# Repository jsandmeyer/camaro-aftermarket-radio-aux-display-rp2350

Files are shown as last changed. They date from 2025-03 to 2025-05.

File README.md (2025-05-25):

## Camaro Temperature & Reverse Sensor Display Shim - RP2350

Picture of the assembled circuit

### Differences from [other repository](https://github.com/jsandmeyer/camaro-aftermarket-radio-aux-display)

This version uses an RP2350 (Raspberry Pi Pico 2 IC) instead of an ATMEGA328PB (Arduino Uno mod).

It takes advantage of the two cores so it can:
1. Listen to the CANBus while rendering is happening, without interrupting either
2. Listen to the CANBus without a CAN controller

### Summary

This provides resources to help you build something to get the temperature display of a PAC RPK5-GM4102 (or 4101) to function while using a Maestro RR instead of the box that came with the PAC kit.
This is useful if you want to have the Maestro functions to get/update vehicle data, but have the nice function and appearance of the OEM-style HVAC knobs provided by the PAC kit.

### Important
This project is not endorsed by GM, the makers of any trim kits (PAC, iDatalink, etc) or my aftermarket radio, any forum or their users, or anyone else, including any entities named in this repository.
It is a personal project that I have completed, and I have accepted a risk to my own property by building and installing this project.

This project (except for PCB footprints supplied by KiCad's included files) is licensed under the MIT license.
Please read the attached LICENSE document.
All code was written by myself, based on documentation provided by libraries or electronic part providers.
All PCB design (except for some footprints) was completed by myself.

### Background

[This forum post on camaro5.com](https://www.camaro5.com/forums/showthread.php?t=588249) goes over the process of combining the two dash kit elements.
Note the OP and others never got the temperature display to work.
This is because the PAC trim component's harness does not have CANBUS access, and the PAC controller was relaying the temperature (and possibly other data) over the Serial line running between the radio and HVAC harnesses.

### Goal

My goal was simply to display the temperature on the OLED.
In the process of design, I also decied to have it show backup sensor data.
The original MyLink radio showed a triangle with an exclamation point in one of five positions over the backup camera when reversing, and it would change color and flash depending on distance.
I wanted to display something similar on the OLED when reversing, because no aftermarket radios seem to support showing the backup sensor data AND camera view at the same time!
The latest version of this module is also able to determine whether the car is displaying metric or imperial units, so there is no need to adjust the jumper on the PCB.

### Reverse Engineering the Hardware

I was able to do some reverse engineering of the PAC RPK5, but without a logic analyzer or serial reading device, I could not do so completely.
I did determine that if I depinned the PAC harness to include only power input, net 5060 low-speed GMLAN, and net 7458 serial data, it would power on and the temperature would display.
However, if I disconnected the TX pin on the PAC controller's internal CANBUS modem (as suggested by its documentation, would force it into "read-only" mode) it would fail completely.
I also discovered that the OLED board used by PAC is a very standard SSD1306 SPI model, and it's roughly equivalent to something you could buy off a hobby site - and the cable connector is also a standard Molex PicoBlade (though the included cable is a crossover cable, likely not made by Molex).

### Reverse Engineering the CANBUS

#### Hardware and Software

I used an Arduino Uno and the [Sparkfun CANBUS shield](https://www.sparkfun.com/products/13262) to prove viability.
With this setup, I was able to snoop on my car's low-speed CANBUS (net 5060) via the main ODB connector using pin 1 for CAN_H and pin 4 for CAN_L and GND.
Using the [mcp_can library](https://github.com/coryjfowler/MCP_CAN_lib) I was able to read temperature and other data.
Eventually, some light googling got me [some details](https://docs.google.com/spreadsheets/d/1pFdixF6W0XK4SR6pXHIlZaFRo9qM5XmAWOK7JcAQdDM/) regarding CANBUS IDs for this car and for other GM cars.

My configuration for this was to:
* Call `CAN0.begin(MCP_STDEXT, CAN_33K3BPS, MCPHZ)` to initialize low-speed CANBUS at 33.3k.
* To configure the filters, I used online resources to try to determine what different ARB IDs meant, and in some cases, even turned off filtering and simply looked through the stream for messages.
* Call `CAN0.setMode(MCP_LISTENONLY)` for read-only CANBUS operation

#### Hardware V2

After confirming this configuration, I switched to using a bare ATMEGA328P chip (similar to the VQFN package I would use in production) and a MCP25625 CAN controller with transciever.
I added ferrite beads to the OLED connector after seeing that PAC decided to use them in their controller board.
I also added a switch to allow selection of Metric vs Imperial units.

#### Hardware V3

This is the first production version.
I added a nice TI power supply designed via Webench, soldered everything down, and also used a jumper to select Metric vs Imperail units (in place of the switch).
Some SMT components are slightly different, like using an AMEGA328PB instead of the ATMEGA328P, or the different footprint of the oscillator.

#### Hardware V6

Versions 4 and 5 had issues which prevented them from going to production.
This version includes mounting holes, extra power supply filtering, a watchdog to reboot the MCU if there are too many errors during boot, and auto-sensing of temperature/distance units instead of using a jumper.
The circuit also uses the 3.3V power supply for all logic except for the CAN transciever, which runs on the base 5V.

#### Hardware V7

This uses an RP2350 MCU instead of an ATMEGA328PB.
See the notes above.

It also uses a TCAN332 transciever instead of the MCP25625 (MCP2551-style).
The IC is effectively a drop-in replacement for the MCP-2551 (except that no slope control resistor is needed).
The main benefit is that it runs on 3.3V, so only one power suppy is necessary (in addition to the 1.1V inside the RP2350).

#### Logs

Temperature was easy to figure out, and was my first step.

For my 2014 Camaro, it comes in as 0x10424060 (raw header), or 0x212 (with mask).
The second byte `buf[1]` contains the temperature... kind-of.
You have to divide the hex value by two, and subtract 40, to get degrees in celsius.

The backup sensors took more work to understand, but were still straightforward.

I found that they were streaming data on 0x103A80BB (raw header), or 0x1D4 (with mask).

The *second nibble* of the first byte `buf[0] & 0x0F` indicates the park-assist staus.
A value of `0` indicates park-assist is ON, and a value of `F` indicates it is OFF.
The *first nibble* `buf[0] & 0xF0` seems related to something else, and also seemed to vary.

The Bosch parking assist unit seems to report the direction and distance to the *closest* object only.
The second byte `buf[1]` contains the distance, in cm, from 0-255cm.

The position is more complicated.
The Bosch unit has four sensors, but reports three positional channels: Middle, Right, and Left.
It may report a single positional channel, or two adjacent channels, to form five possible locations to render the warning triangle!
The position comes out in bytes 3-4 `buf[2-3]`, split into nibbles indicating positions `[M, R], [N/A, L]`.
A value of 0 indicates the channel is off, but values of 1 thorugh 5 indicate the relative "closeness" and beep/flash speed, with 1 being closest and 5 being furthest.
If two channels are activated, such as to indicate a middle-left obstruction, both channels would have the same value.
I also decided it would be prudent to have a timeout to turn off park-assist display if no data was received, in case the MCU missed the "off" signal.

Lastly, I decided to use data from ARB ID 0x425 to decide whether to use Imperial or Metric units.
The vehicle sends this data multiple times upon startup, so devices using only ACC power (like this) can receive it.

### Assembly

**WARNING: DO THIS ALL AT YOUR OWN RISK.  YOU MAY DAMAGE YOUR CAR OR OTHER EQUIPMENT.  MY DESIGNS PROBABLY HAVE FLAWS; I AM A WEB SOFTWARE ENGINEER AFTER ALL.**

The minimum for this to work is that you need the entire PAC kit, a Maestro RR and its standard cables, and a harness to connect the Maestro RR to the camaro.
For the main harness, you can use the one that comes with the complete iDatalink kit, or just the HRN-HRR-GM2 if you want to re-pin the harness (mandatory).

If you use the harness with the iDatalink trim kit, just leave the HVAC connector and trim connector hanging.
For the cheap option, I originally removed pins 2, 13, 20, and 23 from the HRN-HRR-GM2 to make it seem to work.
If you are particularly clever, you might be able to figure out how to wire in the car's microphone to the harness, like the PAC kit does, and connect it to a 3.5mm jack for the radio.
However, for my final build, I did use the harness included in the KIT-CAM1 with the HVAC control disconnected.

I spliced into the 5060 Low-Speed GMLAN cable, the GND line, and the red "accessory power" line between the Maestro RR unit and my aftermarket radio to power the circuit board.

I used a non-crossover Molex Picoblade cable (pre-assembled, Molex part number 0151340703) to connect the circuit board to the OLED display.
I had to temporarily remove a retaining clip from the RPK5 trim to install the cable.
The cable included in the RPK5 is a crossover cable, **please do not use the included display cable for this project** since all the pins will be backwards.
The connector on this project was designed to match the use of a longer cable from Molex; and was *not* based on the design in the trim kit.

See my analysis of the various harness connector configurations in the `resources/2014 camaro connectors.xlsx` file in this repository.

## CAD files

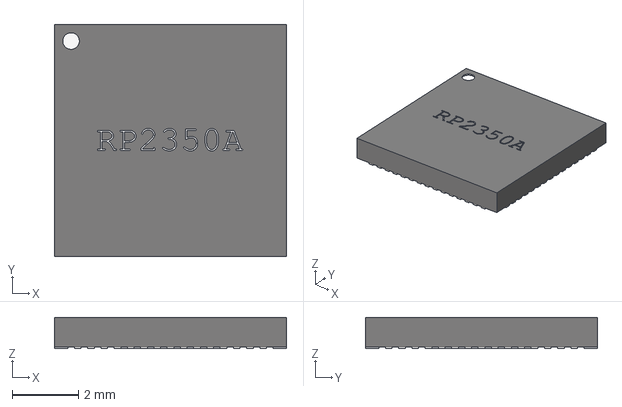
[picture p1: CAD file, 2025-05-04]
pcb/RP2350_QFN60.step
7.00 x 7.00 x 0.95 mm

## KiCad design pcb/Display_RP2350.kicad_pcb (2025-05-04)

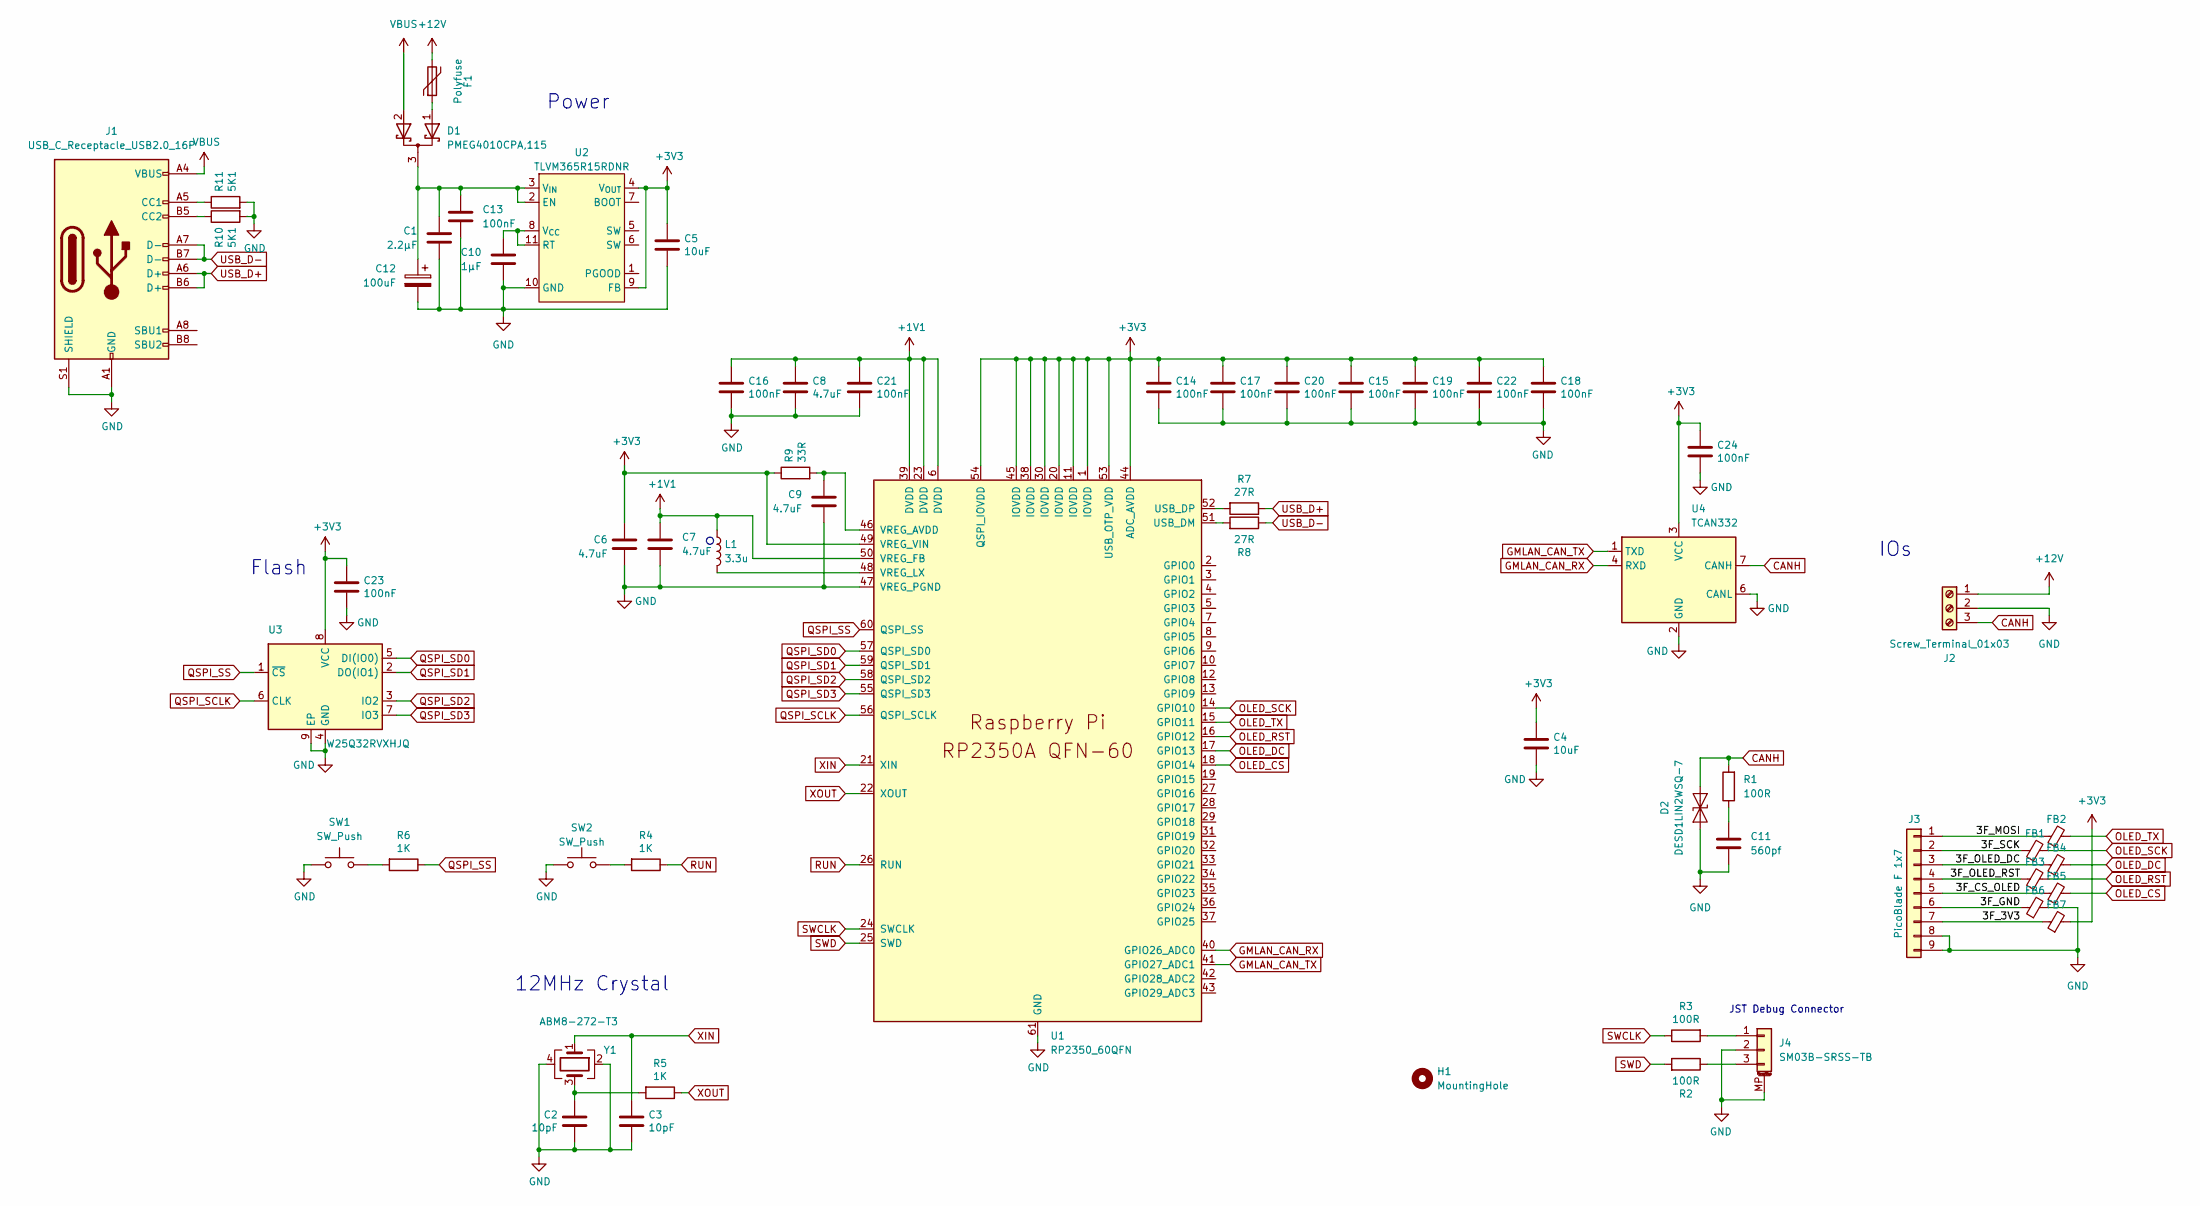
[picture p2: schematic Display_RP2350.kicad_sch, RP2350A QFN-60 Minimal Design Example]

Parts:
C1: 2.2µF; C_1206_3216Metric
C2, C3: 10pF; C_0402_1005Metric
C4, C5: 10uF; C_0805_2012Metric
C6, C7: 4.7uF; C_0402_1005Metric_small_pads
C8, C9: 4.7uF; C_0402_1005Metric
C10: 1µF; C_0603_1608Metric
C11: 560pf; C_0402_1005Metric
C12: 100uF; CP_Elec_6.3x7.7
C13, C14, C15, C16, C17, C18, C19, C20, C21, C22, C23, C24: 100nF; C_0402_1005Metric
D1: PMEG4010CPA,115; HUSON-3-1EP_2x2mm_P1.3mm_EP1.1x1.6mm
D2: DESD1LIN2WSQ-7; D_SOD-323
F1: Polyfuse; Fuse_1206_3216Metric
FB1, FB2, FB3, FB4, FB5, FB6, FB7: 120X; L_0402_1005Metric
H1: MountingHole; MountingHole_2.2mm_M2_ISO14580
J1: USB_C_Receptacle_USB2.0_16P; USB_C_Receptacle_GCT_USB4105-xx-A_16P_TopMnt_Horizontal
J2: Screw_Terminal_01x03; TerminalBlock_3P
J3: PicoBlade F 1x7; CON_532610771_MOD
J4: SM03B-SRSS-TB; JST_SH_SM03B-SRSS-TB_1x03-1MP_P1.00mm_Horizontal
L1: 3.3u; L_pol_2016
R1, R2, R3: 100R; R_0402_1005Metric
R4, R5, R6: 1K; R_0402_1005Metric
R7, R8: 27R; R_0402_1005Metric
R9: 33R; R_0402_1005Metric
R10, R11: 5K1; R_0402_1005Metric
SW1, SW2: SW_Push; SW_Push_1P1T_NO_Vertical_Wuerth_434133025816
U1: RP2350_60QFN; QFN-60-1EP_7x7mm_P0.4mm_EP3.4x3.4mm
U2: TLVM365R15RDNR; QFN-FCMOD_TI_11B
U3: W25Q32RVXHJQ; Winbond_USON-8-1EP_3x2mm_P0.5mm_EP0.2x1.6mm
U4: TCAN332; TSOT-23-8
Y1: ABM8-272-T3; Crystal_SMD_3225-4Pin_3.2x2.5mm

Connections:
+1V1: C7.1, C8.1, C16.1, C21.1, L1.1, U1.6 (DVDD), U1.23 (DVDD), U1.39 (DVDD), U1.50 (VREG_FB)
+3V3: C4.1, C5.1, C6.1, C14.1, C15.1, C17.1, C18.1, C19.1, C20.1, C22.1, C23.1, C24.1, FB7.2, R9.1, U1.1 (IOVDD), U1.11 (IOVDD), U1.20 (IOVDD), U1.30 (IOVDD), U1.38 (IOVDD), U1.44 (ADC_AVDD), U1.45 (IOVDD), U1.49 (VREG_VIN), U1.53 (USB_OTP_VDD), U1.54 (QSPI_IOVDD), U2.4 (V_{OUT}), U2.9 (FB), U3.8 (VCC), U4.3 (VCC)
+12V: F1.2, J2.1
/3F_3V3: FB7.1, J3.7
/3F_CS_OLED: FB5.1, J3.5
/3F_GND: FB6.1, J3.6
/3F_MOSI: FB2.1, J3.1
/3F_OLED_DC: FB4.1, J3.3
/3F_OLED_RST: FB3.1, J3.4
/3F_SCK: FB1.1, J3.2
CANH: D2.2 (A2), J2.3, R1.2, U4.7 (CANH)
GMLAN_CAN_RX: U1.40 (GPIO26_ADC0), U4.4 (RXD)
GMLAN_CAN_TX: U1.41 (GPIO27_ADC1), U4.1 (TXD)
GND: C1.2, C2.2, C3.2, C4.2, C5.2, C6.2, C7.2, C8.2, C9.2, C10.2, C11.2, C12.2, C13.2, C14.2, C15.2, C16.2, C17.2, C18.2, C19.2, C20.2, C21.2, C22.2, C23.2, C24.2, D2.1 (A1), FB6.2, J1.A1 (GND), J1.A12 (GND), J1.B1 (GND), J1.B12 (GND), J1.S1 (SHIELD), J2.2, J3.8, J3.9, J4.2, J4.MP (MountPin), R10.2, R11.2, SW1.1, SW2.2, U1.47 (VREG_PGND), U1.61 (GND), U2.10 (GND), U3.4 (GND), U3.9 (EP), U4.2 (GND), U4.6 (CANL), Y1.2, Y1.4
unnamed: C2.1, R5.2, Y1.3
unnamed: C11.1, R1.1
unnamed: D1.1 (A), F1.1
unnamed: C1.1, C12.1, C13.1, D1.3 (K), U2.2 (EN), U2.3 (V_{IN})
unnamed: J1.A5 (CC1), R11.1
unnamed: J1.B5 (CC2), R10.1
unnamed: J4.1, R3.2
unnamed: J4.3, R2.1
unnamed: R4.2, SW2.1
unnamed: R6.2, SW1.2
unnamed: R8.2, U1.51 (USB_DM)
unnamed: R7.2, U1.52 (USB_DP)
unnamed: C9.1, R9.2, U1.46 (VREG_AVDD)
unnamed: L1.2, U1.48 (VREG_LX)
unnamed: C10.1, U2.8 (V_{CC}), U2.11 (RT)
OLED_CS: FB5.2, U1.18 (GPIO14)
OLED_DC: FB4.2, U1.17 (GPIO13)
OLED_RST: FB3.2, U1.16 (GPIO12)
OLED_SCK: FB1.2, U1.14 (GPIO10)
OLED_TX: FB2.2, U1.15 (GPIO11)
QSPI_SCLK: U1.56 (QSPI_SCLK), U3.6 (CLK)
QSPI_SD0: U1.57 (QSPI_SD0), U3.5 (DI(IO0))
QSPI_SD1: U1.59 (QSPI_SD1), U3.2 (DO(IO1))
QSPI_SD2: U1.58 (QSPI_SD2), U3.3 (IO2)
QSPI_SD3: U1.55 (QSPI_SD3), U3.7 (IO3)
QSPI_SS: R6.1, U1.60 (QSPI_SS), U3.1 (~CS)
RUN: R4.1, U1.26 (RUN)
SWCLK: R3.1, U1.24 (SWCLK)
SWD: R2.2, U1.25 (SWD)
USB_D+: J1.A6 (D+), J1.B6 (D+), R7.1
USB_D-: J1.A7 (D-), J1.B7 (D-), R8.1
VBUS: D1.2 (A), J1.A4 (VBUS), J1.A9 (VBUS), J1.B4 (VBUS), J1.B9 (VBUS)
XIN: C3.1, U1.21 (XIN), Y1.1
XOUT: R5.1, U1.22 (XOUT)

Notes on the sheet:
JST Debug Connector
IOs
Flash
12MHz Crystal
Power

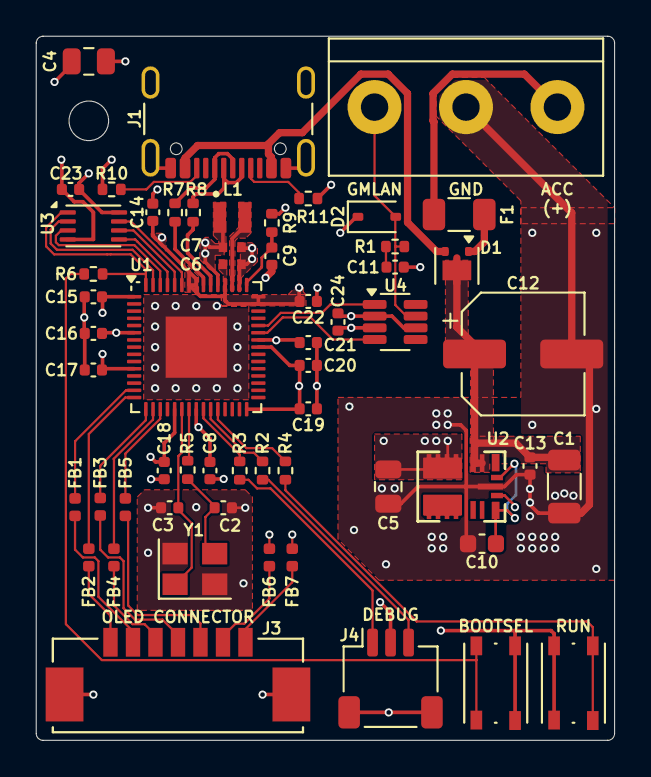
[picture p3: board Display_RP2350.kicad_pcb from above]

Board: 4 copper layers, 32.1 x 39.1 mm, 58 parts (0 on the bottom side), 48 nets.

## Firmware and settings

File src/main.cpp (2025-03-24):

#include <RP2350Wrapper.h> // must include first to avoid warnings
#include <SerialUSB.h>
#include <can2040.h>
#include <pico/util/queue.h>

#include "util/Debug.h"
#include "util/Flash.h"

#include "Core0.h"
#include "Core1.h"

constexpr auto SER_BAUD = 115200UL;
bool core1_separate_stack = true;

static queue_t messageQueue;

static Core0* core0 = nullptr;
static Core1* core1 = nullptr;

void setup() {
    DEBUG(Serial.begin(SER_BAUD));
    DEBUG(Serial.print("Starting core0\n"));

    Flash::setDefaults();

    queue_init(&messageQueue, sizeof(CAN2040::Message), 128);

    rp2040.fifo.push_nb(0xFFFF);
    DEBUG(Serial.print("Core0 init fifo sent\n"));

    core0 = new Core0(&messageQueue);
}

void loop() {
    NO_DEBUG(tight_loop_contents());
    Debug::processDebugInput(&messageQueue);
}

void setup1() {
    DEBUG(Serial.print("Starting core1\n"));

    // wait for ready message
    while (rp2040.fifo.pop() != 0xFFFF) {
        tight_loop_contents();
    }

    DEBUG(Serial.print("Core1 init fifo acquired\n"));

    core1 = new Core1(&messageQueue);
}

void loop1() {
    core1->processMessage();
    core1->renderDisplay();
}

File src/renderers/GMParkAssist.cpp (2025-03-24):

#include <SerialUSB.h>
#include <Adafruit_GFX.h>
#include <Adafruit_SSD1306.h>
#include <Fonts/FreeSans9pt7b.h>
#include <math.h>

#include "GMParkAssist.h"
#include "Renderer.h"
#include "util/Debug.h"
#include "util/GMLan.h"
#include "util/OLED.h"
#include "util/TextHelper.h"

/**
 * Renders the Park Assist rectangle, blanking out the rectangle zone first
 * Rectangle will be rendered visible or invisible based on millis()
 * Does not update display
 */
void GMParkAssist::renderMarkerRectangle() const {
    const auto now = millis();
    display->fillRect(
        0,
        SCREEN_HEIGHT - PA_BAR_H,
        SCREEN_WIDTH,
        PA_BAR_H,
        SSD1306_BLACK
    );

    if (
        parkAssistLevel > 0
        && parkAssistLevel < 5
        && now % parkAssistDisplayMod[parkAssistLevel] < parkAssistDisplayCompare[parkAssistLevel]
    ) {
        display->fillRect(
            PA_BAR_MARGIN + PA_BAR_W * parkAssistSlot,
            SCREEN_HEIGHT - PA_BAR_H,
            PA_BAR_W + PA_BAR_EXTRA_W,
            PA_BAR_H,
            SSD1306_WHITE
        );
    }
}

/**
 * Renders the Park Assist distance, assumes the display is already blank
 * Does not update display
 */
void GMParkAssist::renderDistance() const {
    // max text size is realistically 9 - examples "255cm" or "12in" or "21ft 3in" or "20ft 10in"
    char text[12];

    if (units == GMLAN_VAL_CLUSTER_UNITS_IMPERIAL) {
        // convert cm to inches, then divide out feet
        auto inches = static_cast<uint8_t>(lround(CM_PER_IN * parkAssistDistance));
        const auto feet = inches / 12;
        inches -= feet * 12;

        // only show feet if there is at least 1 foot
        if (feet > 0) {
            snprintf(text, 11, "%dft %din", feet, inches);
        } else {
            snprintf(text, 11, "%din", inches);
        }
    } else {
        snprintf(text, 11, "%dcm", parkAssistDistance);
    }

    // distance text display
    uint16_t width;
    uint16_t height;
    display->setTextSize(1);
    display->setTextColor(SSD1306_WHITE);
    display->setFont(&FreeSans9pt7b);
    TextHelper::getTextBounds(display, text, &FreeSans9pt7b, &width, &height);
    display->setCursor(static_cast<int16_t>(SCREEN_WIDTH - width) / 2, static_cast<int16_t>(height));
    display->write(text);
}

/**
 * Handles the Rear Park Assist "OFF" message
 */
void GMParkAssist::processParkAssistDisableMessage() {
    DEBUG(Serial.print("PA OFF\n"));

    // blanking out all data will prevent future render
    lastTimestamp = 0;
    parkAssistDistance = 0;
    parkAssistLevel = 0;
    parkAssistSlot = 0;
    needsRender = false;
}

/**
 * Handles the Rear Park Assist "ON" message
 * @param buf is the buffer data from GMLAN
 */
void GMParkAssist::processParkAssistInfoMessage(const uint8_t buf[8]) {
    /*
     * buf[1] is shortest real distance to nearest object, from 0x00 to 0xFF, in centimeters
     * rendering function will multiply by 0.0328084 for inches if selected
     */

    DEBUG(Serial.printf("PA ON, distance: %ucm\n", buf[1]));

    lastTimestamp = millis() | 1; // never 0 because of bool evaluation elsewhere; value being 1 ms off is OK
    parkAssistDistance = buf[1];

    /*
     * The park assist sensor controller takes 4 sensor streams and pushes them into 3 data streams for lef/mid/right
     * an obstruction can exist in one nibble, or two adjacent nibbles, creating five total combinations.  The goal is
     * to determine the position of the rectangle from five possible positions, and its blink rate.
     * It is OK to assume that in a multi-nibble scenario (like L+M) that the values will match.
     * buf[2] and buf[3] nibbles are [M, R] and [0, L]
     * for each nibble:
     *  0 = nothing seen
     *  1 = stop (red, solid image/beep)
     *  2 = close (red, blinking/beeping fast)
     *  3 = medium (yellow, blinking/beeping medium)
     *  4 = far (yellow, blinking/beeping slow)
     * Example: buf[2], buf[3] == 0b00100010 (0x22), 0b00000000 (0x00) means M+R at level 2 (close)
     */

    const uint8_t slot_m = (buf[2] & 0xF0) >> 4;
    const uint8_t slot_r = buf[2] & 0x0F;
    const uint8_t slot_l = buf[3] & 0x0F;

    if (slot_m) {
        // middle slot active, so obstruction is mid-left, mid, or mid-right
        parkAssistLevel = slot_m;
        if (slot_l) {
            // left slot also active, so obstruction is mid-left
            parkAssistSlot = 1;
        } else if (slot_r) {
            // right slot also active, so obstruction is mid-right
            parkAssistSlot = 3;
        } else {
            // only middle slot, so obstruction is in the middle
            parkAssistSlot = 2;
        }
    } else if (slot_l) {
        // only left slot, so obstruction is only seen by left sensor
        parkAssistLevel = slot_l;
        parkAssistSlot = 0;
    } else if (slot_r) {
        // only right slot, so obstruction is only seen by right sensor
        parkAssistLevel = slot_r;
        parkAssistSlot = 4;
    } else {
        // should not happen, assume middle
        parkAssistLevel = 0;
        parkAssistSlot = 2;
    }

    // will force render of distance text on next call to render()
    needsRender = true;
}

/**
 * Create a GMParkAssist instance
 * @param display the OLED display from SSD1306 library
 */
GMParkAssist::GMParkAssist(Adafruit_SSD1306* display): Renderer(display) {}

/**
 * Processes the park assist message and sets state
 * @param arbId the arbitration ID GMLAN_MSG_PARK_ASSIST
 * @param buf is the buffer data from GMLAN
 */
void GMParkAssist::processMessage(uint32_t const arbId, uint8_t buf[8]) {
    if (arbId != GMLAN_MSG_PARK_ASSIST) {
        // don't process irrelevant messages
        return;
    }

    /*
     * Right nibble of buf[0] tells whether Rear Park Assist is ON or OFF
     * Left nibble may have unneeded data, so need to mask it out
     */
    const auto state = buf[0] & 0x0F;

    if (state == GMLAN_VAL_PARK_ASSIST_OFF) {
        processParkAssistDisableMessage();
        return;
    }

    if (state == GMLAN_VAL_PARK_ASSIST_ON) {
        processParkAssistInfoMessage(buf);
        return;
    }

    // Don't recognize this message
    DEBUG(Serial.printf("PA Unknown value %u\n", state));
}

/**
 * Renders the current Park Assist display
 * Should only be called if there is something to render
 * Updates the display
 */
void GMParkAssist::render() {
    if (needsRender) {
        display->clearDisplay();
        renderDistance();
        needsRender = false;
    }

    renderMarkerRectangle();
    display->display();
}
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

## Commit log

2025-03-23 Fix canbus startup
2025-03-23 Fix issue in backup sensor
    [GMParkAssist.cpp, main.cpp]
2025-03-24 multicore switch from semaphore to builtin fifo since it's pre-initialized
2025-05-04 Add PCB for RP2350
    [Display_RP2350.kicad_pcb, Display_RP2350.kicad_sch, RP2350_QFN60.step]
2025-05-04 PCB updates
    [Display_RP2350.kicad_pcb, Display_RP2350.kicad_sch]
2025-05-25 Fix incorrect temperature casting
2025-05-25 Update readme & add picture
    [2014 camaro connectors.xlsx]
